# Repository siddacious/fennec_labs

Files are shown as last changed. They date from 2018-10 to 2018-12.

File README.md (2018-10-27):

# Fennec Studios Hamtonio
This is a 'lil board for building into toys. It has:
- Atmel ATSAMD51G19 Cortex m4 processor
- A TPS61029-powered boost converter to run off of batteries
- SWD debug connector
- Winbond 25Q16VJV 2 MB QSPI Flash
- More peripherals than you can throw a stick at
- Runs Circuit Python

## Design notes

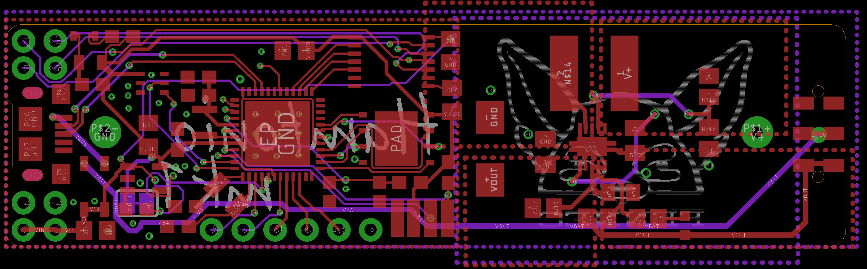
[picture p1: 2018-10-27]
hamtonio.png

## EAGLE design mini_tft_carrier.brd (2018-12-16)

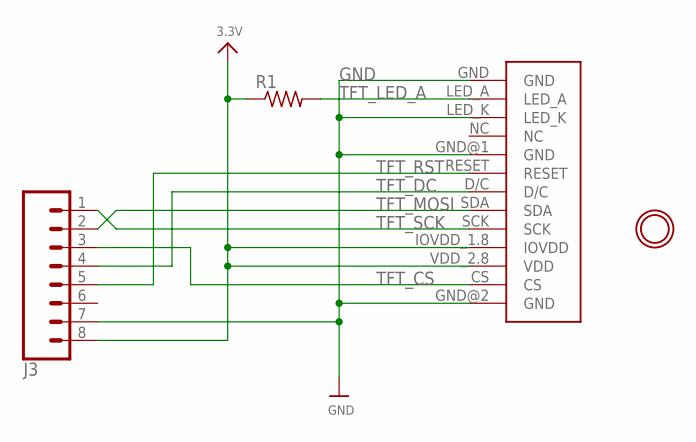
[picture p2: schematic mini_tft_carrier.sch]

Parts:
J3: CONN_08NO_SILK_FEMALE_PTH; 1X08_NO_SILK
R1: R-US_R0603; R0603
U$1: MICRO_TFT
U$2: MOUNTINGHOLE2.5; MOUNTINGHOLE_2.5_PLATED

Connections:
3.3V: J3.8, R1.1, U$1.IOVDD_1.8 (IOVDD), U$1.VDD_2.8 (VDD)
GND: J3.7, U$1.GND, U$1.GND@1 (GND), U$1.GND@2 (GND), U$1.LED_K
TFT_CS: J3.3, U$1.CS
TFT_DC: J3.4, U$1.D/C
TFT_LED_A: R1.2, U$1.LED_A
TFT_MOSI: J3.2, U$1.SDA
TFT_RST: J3.5, U$1.RESET
TFT_SCK: J3.1, U$1.SCK

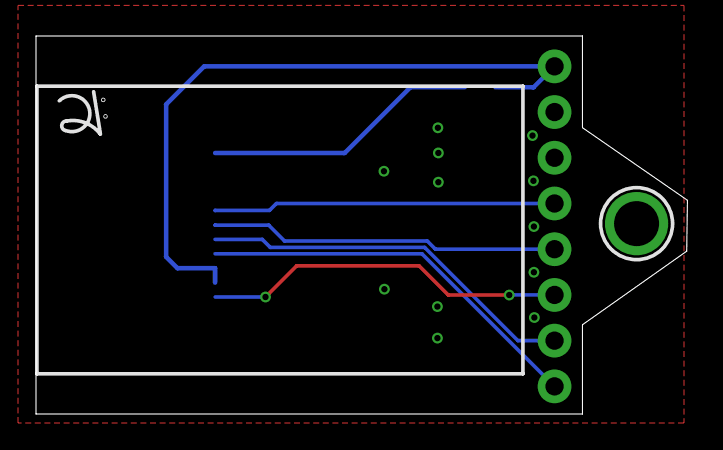
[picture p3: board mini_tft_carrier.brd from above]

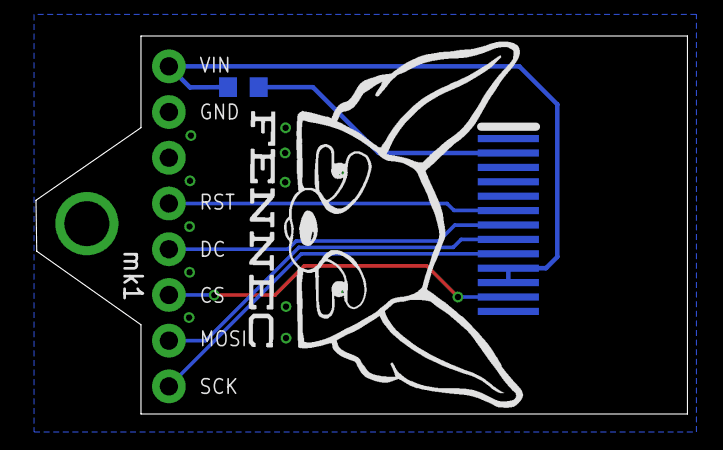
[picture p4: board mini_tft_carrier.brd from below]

Board: 2 copper layers, 36.2 x 21.0 mm, 4 parts (2 on the bottom side), 8 nets.

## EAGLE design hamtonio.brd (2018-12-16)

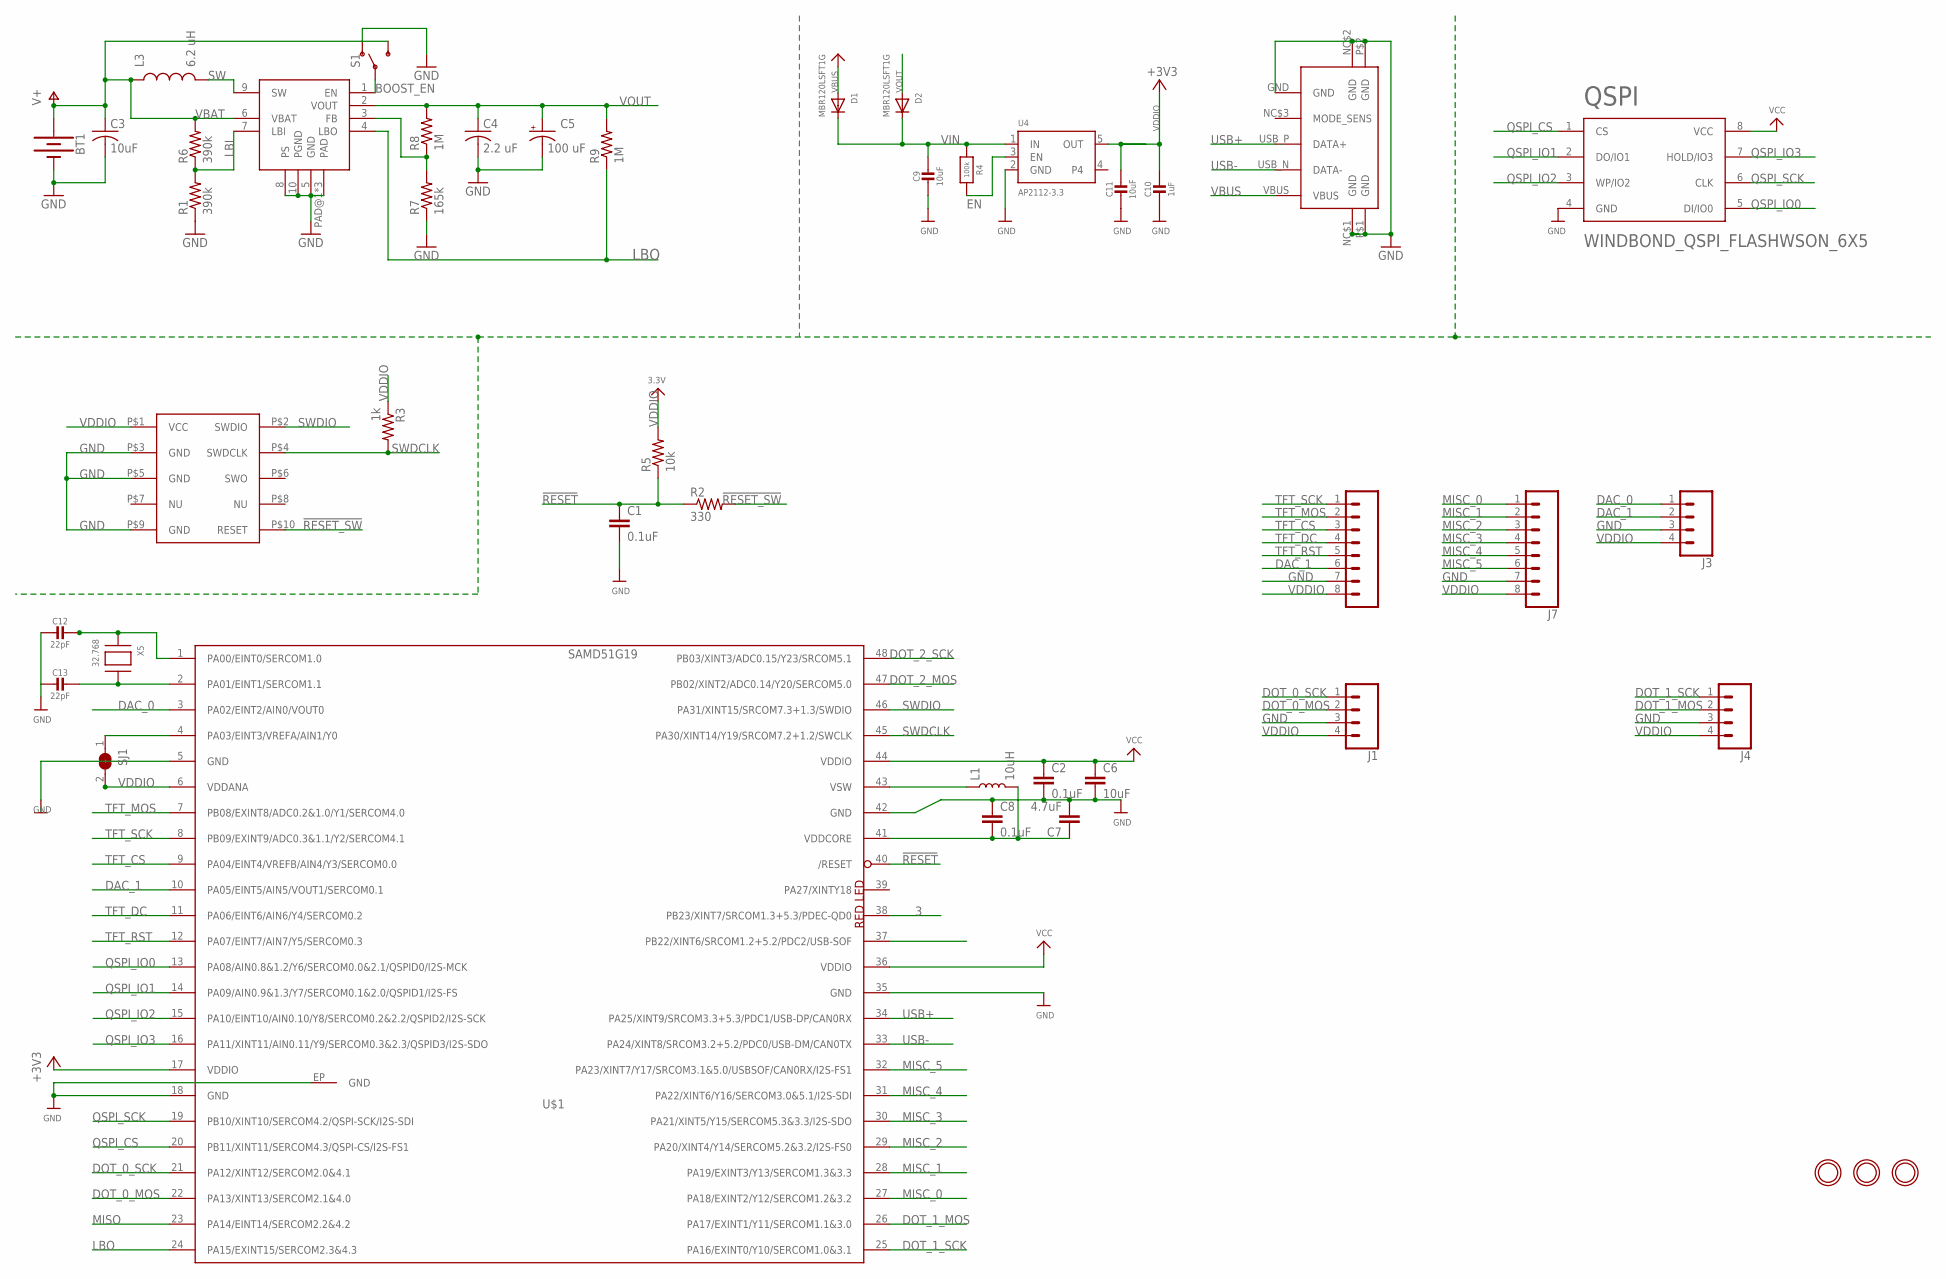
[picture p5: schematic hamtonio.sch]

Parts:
BT1: BATTERYDUAL_AA_XX; DUAL_AA
C1, C2, C8: 0.1uF; 0603
C3: 10uF; C0805K
C4: 2.2 uF; C0805K
C5: 100 uF; CT6032
C6: 10uF; 0805
C7: 4.7uF; 0603
C9, C11: 10uF; 0805-NO
C10: 1uF; 0603-NO
C12, C13: 22pF; 0603-NO
D1, D2: MBR120LSFT1G; SOD-123
J1, J3, J4: CONN_041X04_NO_SILK; 1X04_NO_SILK
J6, J7: CONN_08NO_SILK_FEMALE_PTH; 1X08_NO_SILK
L1: 10uH; 1007_INDUCTOR
L3: 6.2 uH; CDRH52D
QSPI: WINDBOND_QSPI_FLASHWSON_6X5; WSON_6X5MM
R1, R6: 390k; R0603
R2: 330; R0603
R3: 1k; R0603
R4: 100k; 0603-NO
R5: 10k; R0603
R7: 165k; R0603
R8, R9: 1M; R0603
S1: SWITCH-SPDTSMD_C&K_JS; SPDT_SMD
SJ1: SOLDERJUMPERCLOSED; SOLDERJUMPER_CLOSEDWIRE
U4: AP2112-3.3; SOT23-5
U$1: SAMD51G19; QFN-48
U$2: SWD_HEADER; AMPHENOL_SWD
U$8: TPS61029
U$12: AMPHENOL_MICRO_USBAMPHENOL_MICRO_USB_BETTER; BETTER_AMP_MICRO_USB
U$22, U$34, U$39: MOUNTINGHOLE2.5; MOUNTINGHOLE_2.5_PLATED
X5: 32.768; XTAL3215

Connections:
3: U$1.38 (PB23/XINT7/SRCOM1.3+5.3/PDEC-QD0)
!RESET: C1.1, R2.1, R5.1, U$1.40 (/RESET)
!RESET_SW: R2.2, U$2.P$10 (RESET)
AREF: SJ1.1, U$1.4 (PA03/EINT3/VREFA/AIN1/Y0)
BOOST_EN: S1.P$2, S1.P$5, U$8.1 (EN)
DAC_0: J3.1, U$1.3 (PA02/EINT2/AIN0/VOUT0)
DAC_1: J3.2, J6.6, U$1.10 (PA05/EINT5/AIN5/VOUT1/SERCOM0.1)
DOT_0_MOS: J1.2, U$1.22 (PA13/XINT13/SERCOM2.1&4.0)
DOT_0_SCK: J1.1, U$1.21 (PA12/XINT12/SERCOM2.0&4.1)
DOT_1_MOS: J4.2, U$1.26 (PA17/EXINT1/Y11/SERCOM1.1&3.0)
DOT_1_SCK: J4.1, U$1.25 (PA16/EXINT0/Y10/SERCOM1.0&3.1)
DOT_2_MOS: U$1.47 (PB02/XINT2/ADC0.14/Y20/SERCOM5.0)
DOT_2_SCK: U$1.48 (PB03/XINT3/ADC0.15/Y23/SRCOM5.1)
EN: R4.2, U4.3 (EN)
FB: R7.2, R8.1, U$8.3 (FB)
GND: BT1.V- (-), C1.2, C2.2, C3.2, C4.2, C5.-, C6.2, C7.2, C8.1, C9.2, C10.2, C11.2, C12.2, C13.2, J1.3, J3.3, J4.3, J6.7, J7.7, QSPI.4 (GND), R1.1, R7.1, S1.P$1 (O), S1.P$6 (O), U4.2 (GND), U$1.5 (GND), U$1.18 (GND), U$1.35 (GND), U$1.42 (GND), U$1.EP (GND), U$2.P$3 (GND), U$2.P$5 (GND), U$2.P$9 (GND), U$8.5 (GND), U$8.8 (PS), U$8.10 (PGND), U$8.PAD@1 (PAD), U$8.PAD@2 (PAD), U$8.PAD@3 (PAD), U$12.GND, U$12.NC$1 (GND), U$12.NC$2 (GND), U$12.P$1 (GND), U$12.P$2 (GND)
LBI: R1.2, R6.1, U$8.7 (LBI)
LBO: R9.1, U$1.24 (PA15/EXINT15/SERCOM2.3&4.3), U$8.4 (LBO)
MISC_0: J7.1, U$1.27 (PA18/EXINT2/Y12/SERCOM1.2&3.2)
MISC_1: J7.2, U$1.28 (PA19/EXINT3/Y13/SERCOM1.3&3.3)
MISC_2: J7.3, U$1.29 (PA20/XINT4/Y14/SERCOM5.2&3.2/I2S-FS0)
MISC_3: J7.4, U$1.30 (PA21/XINT5/Y15/SERCOM5.3&3.3/I2S-SDO)
MISC_4: J7.5, U$1.31 (PA22/XINT6/Y16/SERCOM3.0&5.1/I2S-SDI)
MISC_5: J7.6, U$1.32 (PA23/XINT7/Y17/SRCOM3.1&5.0/USBSOF/CAN0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)
MISO: U$1.23 (PA14/EINT14/SERCOM2.2&4.2)
QSPI_CS: QSPI.1 (CS), U$1.20 (PB11/XINT11/SERCOM4.3/QSPI-CS/I2S-FS1)
QSPI_IO0: QSPI.5 (DI/IO0), U$1.13 (PA08/AIN0.8&1.2/Y6/SERCOM0.0&2.1/QSPID0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)
QSPI_IO1: QSPI.2 (DO/IO1), U$1.14 (PA09/AIN0.9&1.3/Y7/SERCOM0.1&2.0/QSPID1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)
QSPI_IO2: QSPI.3 (WP/IO2), U$1.15 (PA10/EINT10/AIN0.10/Y8/SERCOM0.2&2.2/QS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)
QSPI_IO3: QSPI.7 (HOLD/IO3), U$1.16 (PA11/XINT11/AIN0.11/Y9/SERCOM0.3&2.3/QS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)
QSPI_SCK: QSPI.6 (CLK), U$1.19 (PB10/XINT10/SERCOM4.2/QSPI-SCK/I2S-SDI)
SW: L3.2, U$8.9 (SW)
SWDCLK: R3.2, U$1.45 (PA30/XINT14/Y19/SRCOM7.2+1.2/SWCLK), U$2.P$4 (SWDCLK)
SWDIO: U$1.46 (PA31/XINT15/SRCOM7.3+1.3/SWDIO), U$2.P$2 (SWDIO)
TFT_CS: J6.3, U$1.9 (PA04/EINT4/VREFB/AIN4/Y3/SERCOM0.0)
TFT_DC: J6.4, U$1.11 (PA06/EINT6/AIN6/Y4/SERCOM0.2)
TFT_MOS: J6.2, U$1.7 (PB08/EXINT8/ADC0.2&1.0/Y1/SERCOM4.0)
TFT_RST: J6.5, U$1.12 (PA07/EINT7/AIN7/Y5/SERCOM0.3)
TFT_SCK: J6.1, U$1.8 (PB09/EXINT9/ADC0.3&1.1/Y2/SERCOM4.1)
USB+: U$1.34 (PA25/XINT9/SRCOM3.3+5.3/PDC1/USB-DP/CAN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), U$12.USB_P (DATA+)
USB-: U$1.33 (PA24/XINT8/SRCOM3.2+5.2/PDC0/USB-DM/CAN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), U$12.USB_N (DATA-)
VBAT: BT1.V+ (+), C3.1, L3.1, R6.2, S1.P$3 (S), S1.P$4 (S), U$8.6 (VBAT)
VBUS: D1.A, U$12.VBUS
VDDCORE: C7.1, C8.2, L1.P$2 (2), U$1.41 (VDDCORE)
VDDIO: C2.1, C6.1, C10.1, C11.1, J1.4, J3.4, J4.4, J6.8, J7.8, QSPI.8 (VCC), R3.1, R5.2, SJ1.2, U4.5 (OUT), U$1.6 (VDDANA), U$1.17 (VDDIO), U$1.36 (VDDIO), U$1.44 (VDDIO), U$2.P$1 (VCC)
VIN: C9.1, D1.C, D2.C, R4.1, U4.1 (IN)
VOUT: C4.1, C5.+, D2.A, R8.2, R9.2, U$8.2 (VOUT)
VSW: L1.P$1 (1), U$1.43 (VSW)
XOSC32_A: C12.1, U$1.1 (PA00/EINT0/SERCOM1.0), X5.P$1
XOSC32_B: C13.1, U$1.2 (PA01/EINT1/SERCOM1.1), X5.P$2

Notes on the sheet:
RED LED

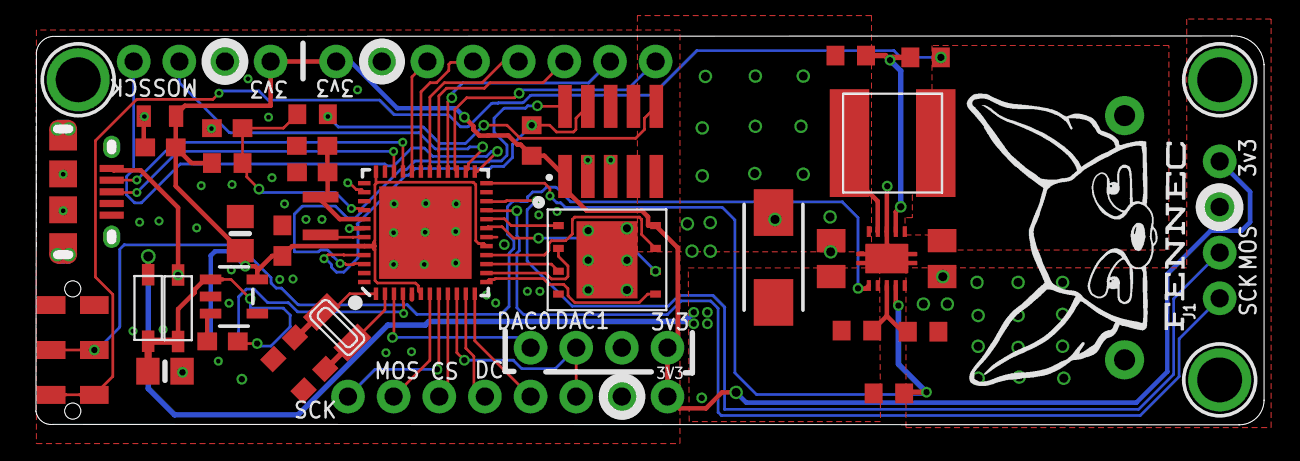
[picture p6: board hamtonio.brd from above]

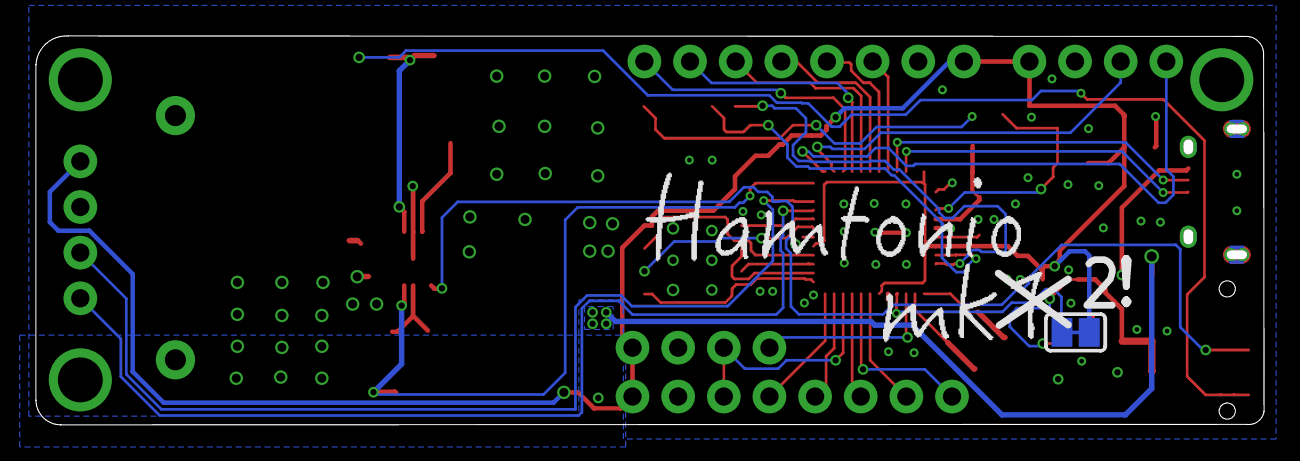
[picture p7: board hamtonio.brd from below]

Board: 2 copper layers, 68.3 x 21.6 mm, 44 parts (2 on the bottom side), 46 nets.

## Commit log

2018-10-27 first working commit; OSH Park 8J7wCeam
    [hamtonio.brd, hamtonio.sch]
2018-10-27 tft carrier v1
    [mini_tft_carrier.brd, mini_tft_carrier.sch]
2018-10-31 tft carrier and hamtonio mkx2; Oshpark MKiCLdFX
    [hamtonio.brd, hamtonio.sch]
2018-12-16 backin' up
    [hamtonio.brd, hamtonio.sch, mini_tft_carrier.brd]

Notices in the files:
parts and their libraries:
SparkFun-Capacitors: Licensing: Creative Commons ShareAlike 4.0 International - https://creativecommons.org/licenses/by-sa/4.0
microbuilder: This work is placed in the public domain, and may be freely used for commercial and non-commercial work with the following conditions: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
